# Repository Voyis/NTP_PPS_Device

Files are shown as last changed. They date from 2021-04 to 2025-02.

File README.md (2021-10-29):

# NTP_PPP_Device
ESP32 based board that mimics an GPS with PPS, but using NTP.

## Software Install

This project uses the Arduino library to build the code and flash it onto the ESP32-WROOM-32 from Espressif. After installing the Arduino IDE, you have to first instal the Adafruit SSD1360 library and all it's dependencies. You also need to install the [ESP32 board package](https://docs.espressif.com/projects/arduino-esp32/en/latest/installing.html#installing-using-boards-manager).

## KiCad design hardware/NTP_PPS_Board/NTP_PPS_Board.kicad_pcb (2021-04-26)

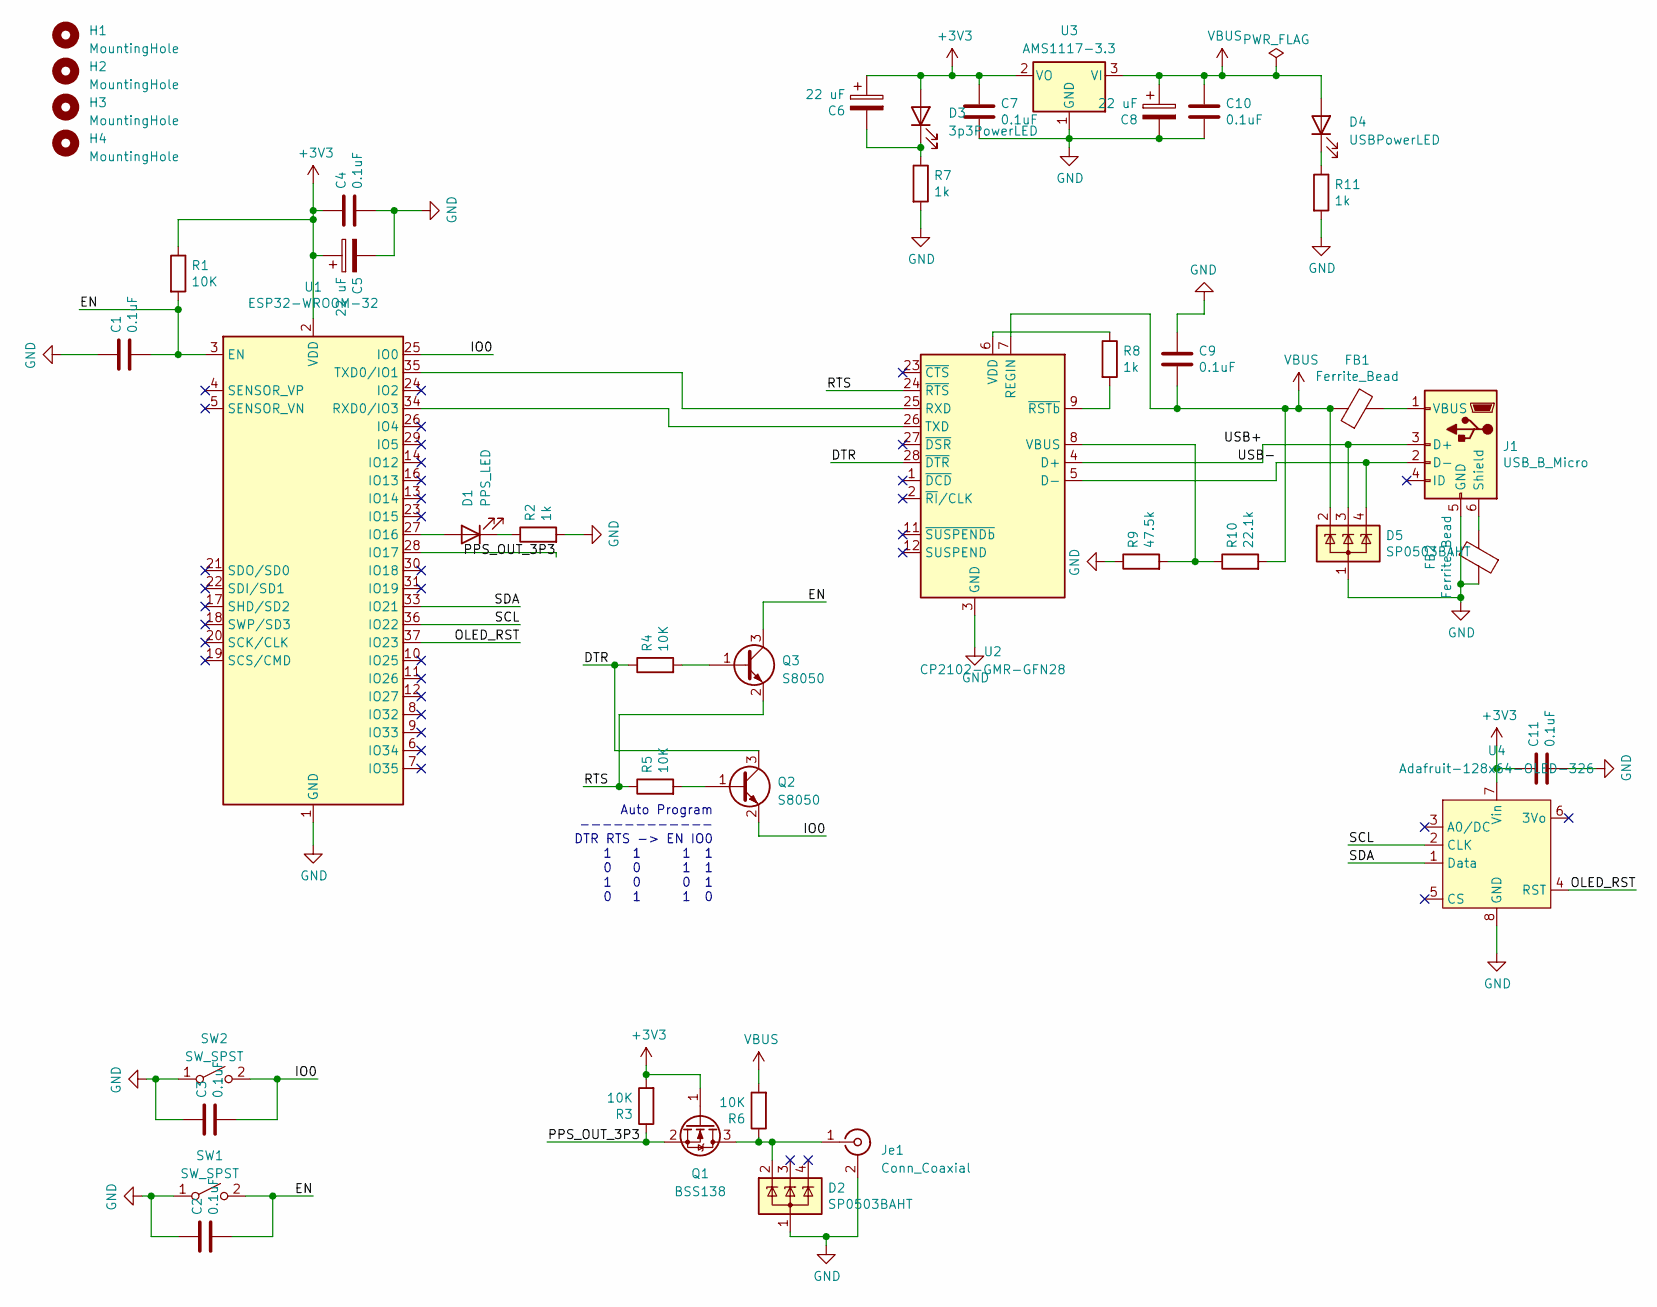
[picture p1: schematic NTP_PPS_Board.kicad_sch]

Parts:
C1, C2, C3, C4, C7, C9, C10, C11: 0.1uF; C_0603_1608Metric; LCSC Part # C14663
C5, C6, C8: 22 uF; CP_Elec_6.3x5.4; LCSC Part # C27783
D1: PPS_LED; LED_0603_1608Metric; LCSC Part # C74343
D2, D5: SP0503BAHT; SOT-143; LCSC Part # C7074
D3: 3p3PowerLED; LED_0603_1608Metric; LCSC Part # C72044
D4: USBPowerLED; LED_0603_1608Metric; LCSC Part # C72044
FB1, FB2: Ferrite_Bead; L_0805_2012Metric; LCSC Part # C88993
H1, H2, H3, H4: MountingHole; MountingHole_3.2mm_M3
J1: USB_B_Micro; MicroUSB-5.9mm; LCSC Part # C393940
Je1: Conn_Coaxial; BNC_TEConnectivity_1478204_Vertical; Digikey Part # A97581-ND
Q1: BSS138; SOT-23; LCSC Part # C112239
Q2, Q3: S8050; SOT-23; LCSC Part # C727137
R1, R3, R4, R5, R6: 10K; R_0603_1608Metric; LCSC Part # C269701
R2, R7, R8, R11: 1k; C_0603_1608Metric; LCSC Part # C269349
R9: 47.5k; R_0603_1608Metric; LCSC Part # C325696
R10: 22.1k; R_0603_1608Metric; LCSC Part # C269476
SW1, SW2: SW_SPST; SW_Push_1P1T_NO_6x6mm_H9.5mm; LCSC Part # C2686880
U1: ESP32-WROOM-32; Digikey Part # 1965-ESP32-WROOM-32E(4MBHIGHTEMP)CT-ND
U2: CP2102-GMR-GFN28; QFN-28-1EP_5x5mm_P0.5mm_EP3.35x3.35mm; LCSC Part # C6568
U3: AMS1117-3.3; SOT-223-3_TabPin2; LCSC Part # C351784
U4: Adafruit-128x64-OLED-326; AdaFruit-0.86-OLED

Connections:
+3V3: C4.1, C5.1, C6.1, C7.1, C11.1, D3.2 (A), Q1.1 (G), R1.1, R3.2, U1.2 (VDD), U3.2 (VO), U4.7 (Vin)
/DTR: Q2.3 (C), R4.1, U2.28 (~DTR)
/EN: C1.2, C2.2, Q3.3 (C), R1.2, SW1.2 (B), U1.3 (EN)
/IO0: C3.2, Q2.2 (E), SW2.2 (B), U1.25 (IO0)
/OLED_RST: U1.37 (IO23), U4.4 (RST)
/PPS_OUT_3P3: Q1.2 (S), R3.1, U1.28 (IO17)
/RTS: Q3.2 (E), R5.1, U2.24 (~RTS)
/SCL: U1.36 (IO22), U4.2 (CLK)
/SDA: U1.33 (IO21), U4.1 (Data)
/USB+: D5.3 (K), J1.3 (D+), U2.4 (D+)
/USB-: D5.4 (K), J1.2 (D-), U2.5 (D-)
GND: C1.1, C2.1, C3.1, C4.2, C5.2, C7.2, C8.2, C9.1, C10.2, C11.2, D2.1 (A), D5.1 (A), FB2.1, J1.5 (GND), Je1.2 (Ext), R2.2, R7.2, R9.1, R11.2, SW1.1 (A), SW2.1 (A), U1.1 (GND), U1.15 (GND), U1.38 (GND), U1.39 (GND), U2.3 (GND), U2.29 (GND), U3.1 (GND), U4.8 (GND)
unnamed: C6.2, D3.1 (K), R7.1
unnamed: D1.1 (K), R2.1
unnamed: D1.2 (A), U1.27 (IO16)
unnamed: D2.2 (K), Je1.1 (In), Q1.3 (D), R6.1
unnamed: D4.1 (K), R11.1
unnamed: FB1.2, J1.1 (VBUS)
unnamed: FB2.2, J1.6 (Shield)
unnamed: Q2.1 (B), R5.2
unnamed: Q3.1 (B), R4.2
unnamed: R8.1, U2.6 (VDD)
unnamed: R8.2, U2.9 (~RSTb)
unnamed: R9.2, R10.1, U2.8 (VBUS)
unnamed: U1.34 (RXD0/IO3), U2.26 (TXD)
unnamed: U1.35 (TXD0/IO1), U2.25 (RXD)
VBUS: C8.1, C9.2, C10.1, D4.2 (A), D5.2 (K), FB1.1, R6.2, R10.2, U2.7 (REGIN), U3.3 (VI)

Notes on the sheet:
Auto Program ------------ DTR RTS -> EN IO0 1 1 1 1 0 0 1 1 1 0 0 1 0 1 1 0

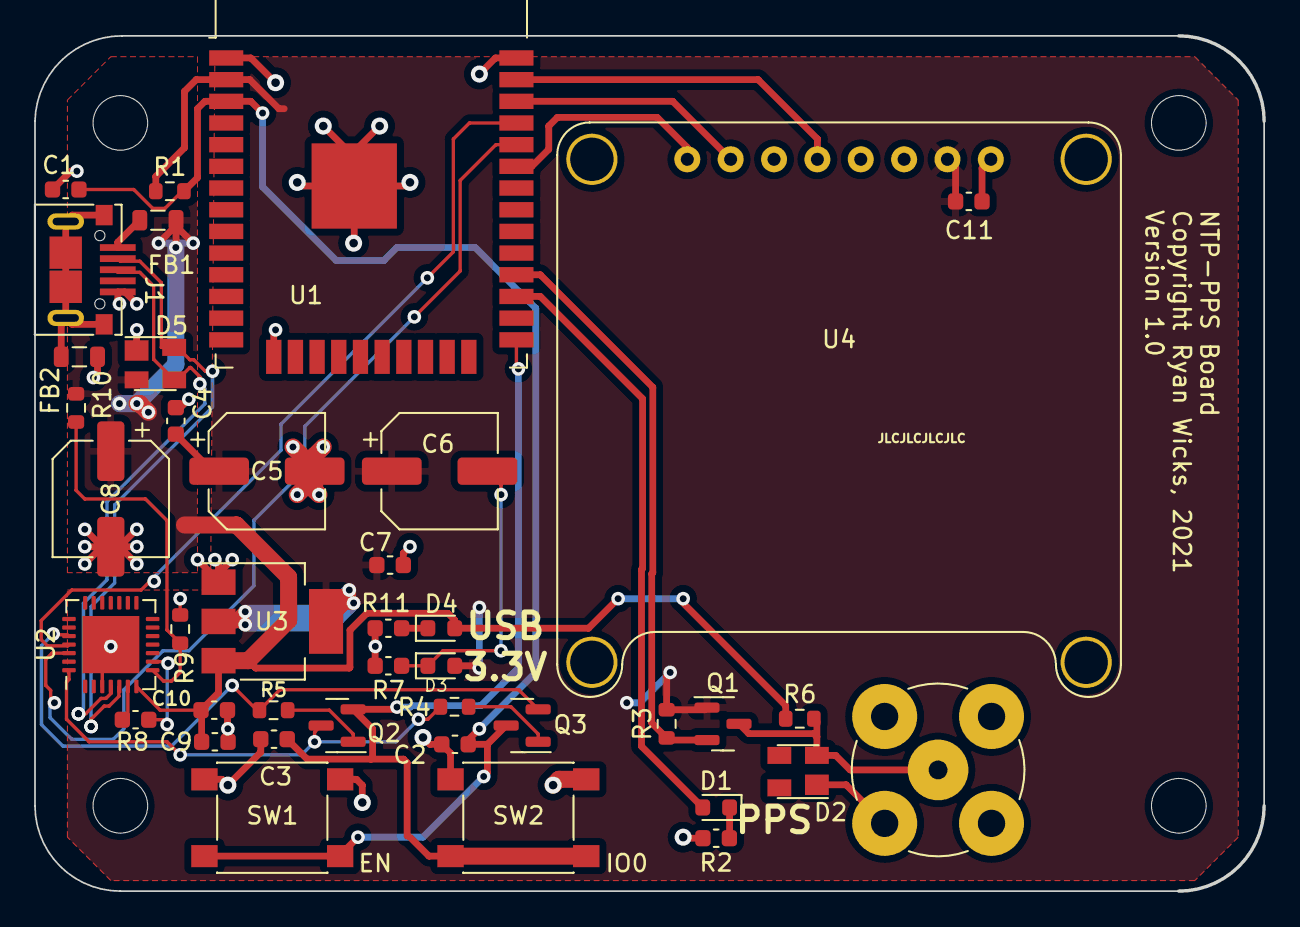
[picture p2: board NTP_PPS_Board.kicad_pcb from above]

Board: 2 copper layers, 72.0 x 50.1 mm, 44 parts (0 on the bottom side), 27 nets.

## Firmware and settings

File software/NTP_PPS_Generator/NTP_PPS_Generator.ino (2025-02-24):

/**
 * NTP_PPP_GENERATOR
 *
 * 9 June 2023
 *
 * This program reads in pps signals an retransmits them at a higher voltage
 *
 * This program connect the NTP-PPS board to a time server, and continually
 * sends out PPS and ZDA pulses every second.
 *
 * It uses the Adafruit SSD1306 library, and any of it's dependencies.
 *
 */

#include <Adafruit_GFX.h>
#include <Adafruit_SSD1306.h>
#include <Arduino.h>
#include <AsyncUDP.h>
#include <WiFi.h>
#include <Wire.h>
#include <esp_sntp.h>
#include <string>
#include <vector>

#include "secrets.h"

#define SCREEN_WIDTH 128 // OLED display width, in pixels
#define SCREEN_HEIGHT 64 // OLED display height, in pixels

#define OLED_RESET -1 // Reset pin # (or -1 if sharing Arduino reset pin)
#define SCREEN_ADDRESS                                                         \
  0x3D ///< See datasheet for Address; 0x3D for 128x64, 0x3C for 128x32
Adafruit_SSD1306 display(SCREEN_WIDTH, SCREEN_HEIGHT, &Wire, OLED_RESET);

const char *ntpServer = "192.168.42.18";
const long gmtOffset_sec = 0;
const int daylightOffset_sec = 0;

const int PPS_OUT_PIN =
    17; // actually gpio 17, but I'm using the DOIT definitions.
const int PPS_OUT_LED = 16;

const int TCP_PORT = 5555;
const int UDP_PORT = 5556;

#define LOGO_HEIGHT 63
#define LOGO_WIDTH 128

static const unsigned char PROGMEM logo_bmp[] = {
    0x00, 0x00, 0x00, 0x00, 0x00, 0x00, 0x00, 0x00, 0x00, 0x00, 0x00, 0x00,
    0x00, 0x00, 0x00, 0x00, 0x00, 0x00, 0x00, 0x00, 0x00, 0x00, 0x00, 0x00,
    0x00, 0x00, 0x00, 0x00, 0x00, 0x00, 0x00, 0x00, 0x00, 0x00, 0x00, 0x00,
    0x00, 0x00, 0x00, 0x00, 0x00, 0x00, 0x00, 0x00, 0x00, 0x00, 0x00, 0x00,
    0x00, 0x00, 0x00, 0x00, 0x00, 0x00, 0x00, 0x00, 0x00, 0x00, 0x00, 0x00,
    0x00, 0x00, 0x00, 0x00, 0x00, 0x00, 0x00, 0x00, 0x00, 0x00, 0x00, 0x00,
    0x00, 0x00, 0x00, 0x00, 0x00, 0x00, 0x00, 0x00, 0x00, 0x00, 0x00, 0x00,
    0x00, 0x00, 0x00, 0x00, 0x00, 0x00, 0x00, 0x00, 0x00, 0x00, 0x00, 0x00,
    0x00, 0x00, 0x00, 0x00, 0x00, 0x00, 0x00, 0x00, 0x00, 0x00, 0x00, 0x00,
    0x00, 0x00, 0x00, 0x00, 0x00, 0x00, 0x00, 0x00, 0x00, 0x00, 0x00, 0x00,
    0x00, 0x00, 0x00, 0x00, 0x00, 0x00, 0x00, 0x00, 0x00, 0x00, 0x00, 0x00,
    0x00, 0x00, 0x00, 0x00, 0x00, 0x00, 0x00, 0x00, 0x00, 0x00, 0x00, 0x00,
    0x00, 0x00, 0x00, 0x00, 0x00, 0x00, 0x00, 0x00, 0x00, 0x00, 0x00, 0x00,
    0x00, 0x00, 0x00, 0x00, 0x00, 0x00, 0x00, 0x00, 0x00, 0x00, 0x00, 0x00,
    0x00, 0x00, 0x00, 0x00, 0x00, 0x00, 0x00, 0x00, 0x00, 0x00, 0x00, 0x00,
    0x00, 0x00, 0x00, 0x00, 0x00, 0x00, 0x00, 0x00, 0x00, 0x00, 0x00, 0x00,
    0x00, 0x00, 0x00, 0x00, 0x00, 0x00, 0x00, 0x00, 0x00, 0x00, 0x00, 0x00,
    0x00, 0x00, 0x00, 0x00, 0x00, 0x00, 0x00, 0x00, 0x00, 0x00, 0x00, 0x00,
    0x00, 0x00, 0x00, 0x00, 0x00, 0x00, 0x00, 0x00, 0x00, 0x00, 0x00, 0x00,
    0x00, 0x00, 0x00, 0x00, 0x00, 0x00, 0x00, 0x00, 0x00, 0x00, 0x00, 0x00,
    0x00, 0x00, 0x00, 0x00, 0x00, 0x00, 0x00, 0x00, 0x00, 0x00, 0x00, 0x00,
    0x00, 0x00, 0x00, 0x00, 0x00, 0x00, 0x00, 0x00, 0x00, 0x00, 0x00, 0x00,
    0x00, 0x00, 0x00, 0x00, 0x00, 0x00, 0x00, 0x00, 0x00, 0x00, 0x00, 0x00,
    0x00, 0x00, 0x00, 0x00, 0x00, 0x00, 0x00, 0x00, 0x00, 0x00, 0x00, 0x00,
    0x00, 0x00, 0x00, 0x00, 0x00, 0x00, 0x00, 0x00, 0x00, 0x00, 0x00, 0x00,
    0x00, 0x00, 0x00, 0x00, 0x00, 0x00, 0x00, 0x00, 0x00, 0x00, 0x00, 0x00,
    0x00, 0x00, 0x00, 0x00, 0x00, 0x00, 0x00, 0x00, 0x00, 0x00, 0x00, 0x00,
    0x00, 0x00, 0x00, 0x00, 0x00, 0x00, 0x00, 0x00, 0x00, 0x00, 0x00, 0x00,
    0x00, 0x00, 0x00, 0x00, 0x00, 0x00, 0x00, 0x00, 0x00, 0x00, 0x00, 0x00,
    0x00, 0x00, 0x00, 0x00, 0x00, 0x00, 0x00, 0x00, 0x00, 0x00, 0x00, 0x00,
    0x00, 0x00, 0x00, 0x00, 0x00, 0x10, 0x00, 0x00, 0x00, 0x00, 0x00, 0x00,
    0x00, 0x00, 0x00, 0x00, 0x00, 0x00, 0x00, 0x00, 0x00, 0x10, 0x00, 0x00,
    0x00, 0x00, 0x00, 0x00, 0x00, 0x00, 0x00, 0x00, 0x00, 0x00, 0x00, 0x00,
    0x00, 0x30, 0x00, 0x00, 0x00, 0x00, 0x00, 0x00, 0x00, 0x00, 0x00, 0x00,
    0x00, 0x00, 0x00, 0x00, 0x00, 0x70, 0x00, 0x00, 0x00, 0x00, 0x00, 0x00,
    0x00, 0x00, 0x00, 0x00, 0x00, 0x00, 0x00, 0x00, 0x00, 0xe0, 0x00, 0x00,
    0x00, 0x00, 0x00, 0x00, 0x00, 0x00, 0x00, 0x00, 0x00, 0x00, 0x00, 0x00,
    0x00, 0xe0, 0x00, 0x00, 0x00, 0x00, 0x00, 0x00, 0x00, 0x00, 0x00, 0x00,
    0x00, 0x00, 0x00, 0x20, 0x01, 0xa0, 0x00, 0x00, 0x00, 0x00, 0x00, 0x00,
    0x00, 0x00, 0x00, 0x00, 0x00, 0x00, 0x00, 0x30, 0x02, 0x80, 0x00, 0x00,
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

hw_timer_t *timer = NULL;
portMUX_TYPE timerMux = portMUX_INITIALIZER_UNLOCKED;

volatile time_t rawtime;
volatile bool second_changed;
char ip_address[16];

WiFiServer server(TCP_PORT);
AsyncUDP udp;
std::vector<WiFiClient> tcp_clients;

/**
 * Generate ZDA and RMC Strings
 */
String generateGPS() {
  struct tm *timeinfo = localtime(const_cast<time_t *>(&rawtime));
  String zda_string;

  // ZDA setup
  char buf[150];
  sprintf(buf, "$GPZDA,%02d%02d%02d.50,%02d,%02d,%04d,00,00*",
          timeinfo->tm_hour, timeinfo->tm_min, timeinfo->tm_sec,
          timeinfo->tm_mday, timeinfo->tm_mon + 1, timeinfo->tm_year + 1900);
  zda_string = String(buf);
  size_t zda_length(zda_string.length());

  uint8_t checksum = 0;
  for (auto i = 0; i < zda_length; ++i) {
    if (buf[i] == '$' || buf[i] == 'I' || buf[i] == '*') {
      continue;
    }
    checksum = checksum ^ buf[i];
  }

  char checkbuf[3];
  sprintf(checkbuf, "%02X", checksum);

  zda_string += checkbuf;
  zda_string += "\r\n";

  // RMC setup
  String rmc_string;

  sprintf(buf,
          "$GPRMC,%02d%02d%02d.00,A,0000.01,N,00000.01,W,0.0,0.0,%02d,%02d,%"
          "04d,0.0,W*",
          timeinfo->tm_hour, timeinfo->tm_min, timeinfo->tm_sec,
          timeinfo->tm_mday, timeinfo->tm_mon + 1, timeinfo->tm_year + 1900);
  rmc_string = String(buf);
  size_t rmc_length(rmc_string.length());

  checksum = 0;
  for (auto i = 0; i < rmc_length; ++i) {
    if (buf[i] == '$' || buf[i] == 'I' || buf[i] == '*') {
      continue;
    }
    checksum = checksum ^ buf[i];
  }

  sprintf(checkbuf, "%02X", checksum);

  rmc_string += checkbuf;
  rmc_string += "\r\n";

  String gps_string;
  gps_string = zda_string + rmc_string;

  return gps_string;
}

/**
 * Method for updating the display.
 */
void printLocalTime() {
  display.clearDisplay();
  display.setCursor(0, 0);
  struct tm *timeinfo = localtime(const_cast<time_t *>(&rawtime));
  display.println(timeinfo, "%B %d %Y\n   %H:%M:%S UTC\n\n");
  display.println("IP Address: ");
  display.println(ip_address);
  display.print("Ports: \nTCP: ");
  display.print(String(TCP_PORT).c_str());
  display.print(" UDP: ");
  display.println(String(UDP_PORT).c_str());
  display.display();

  String gps_string = generateGPS();
  Serial.print((gps_string).c_str());
  udp.broadcastTo((gps_string).c_str(), UDP_PORT);
  for (auto it = tcp_clients.begin(); it != tcp_clients.end(); ++it) {
    if (it->connected()) {
      it->print(gps_string.c_str());
    } else {
      tcp_clients.erase(it);
      --it;
    }
  }
}

/**
 * Interrupt handler for the 1s interrupt.
 */
void IRAM_ATTR onTimer() {
  portENTER_CRITICAL_ISR(&timerMux);
  rawtime += 1;
  digitalWrite(PPS_OUT_PIN, HIGH);
  digitalWrite(PPS_OUT_LED, HIGH);
  second_changed = true;
  portEXIT_CRITICAL_ISR(&timerMux);
}

void setup() {
  Serial.begin(115200);
  Wire.setClock(400000);
  pinMode(PPS_OUT_PIN, OUTPUT);
  pinMode(PPS_OUT_LED, OUTPUT);

  // Set up screen.
  // SSD1306_SWITCHCAPVCC = generate display voltage from 3.3V internally
  if (!display.begin(SSD1306_SWITCHCAPVCC, SCREEN_ADDRESS)) {
    Serial.println(F("SSD1306 allocation failed"));
    for (;;)
      ; // Don't proceed, loop forever
  }
  display.clearDisplay();
  // Show initial display buffer contents on the screen --
  display.drawBitmap(0, 0, logo_bmp, LOGO_WIDTH, LOGO_HEIGHT, 1);
  display.display();
  delay(2000); // Pause for 2 seconds

  display.clearDisplay();
  display.setTextSize(1);
  display.setTextColor(SSD1306_WHITE);
  display.setCursor(25, 0);
  // display.setSize(2);
  display.println("VOYIS NTP PPS");
  display.setCursor(21, 8);
  display.println("Generator V1.0");
  display.display();
  display.printf("\nConnecting to %s\n", WIFI_SSID);
  display.display();
  WiFi.begin(WIFI_SSID, WIFI_PASSWORD);
  while (WiFi.status() != WL_CONNECTED) {
    delay(500);
    display.print(".");
    display.display();
  }
  Serial.println(" CONNECTED");
  IPAddress ip_temp = WiFi.localIP();
  sprintf(ip_address, "%d.%d.%d.%d", ip_temp[0], ip_temp[1], ip_temp[2],
          ip_temp[3]);
  display.display();

  // init and get the time
  struct tm timeinfo;
  configTime(gmtOffset_sec, daylightOffset_sec, ntpServer);
  // sntp_set_sync_interval(15000);
  // sntp_restart();
  if (!getLocalTime(&timeinfo)) {
    display.println("Failed to obtain time");
    return;
  }
  rawtime = mktime(&timeinfo);

  timer = timerBegin(0, 80, true);
  timerAttachInterrupt(timer, &onTimer, true);
  timerAlarmWrite(timer, 1000000, true);
  timerAlarmEnable(timer);

  // disconnect WiFi as it's no longer needed
  // WiFi.disconnect(true);
  // WiFi.mode(WIFI_OFF);
  delay(2000);
  display.clearDisplay();

  server.begin();
}

void loop() {
  // put your main code here, to run repeatedly:
  if (second_changed) {
    second_changed = false;
    printLocalTime();
    delay(100);
    digitalWrite(PPS_OUT_PIN, LOW);
    digitalWrite(PPS_OUT_LED, LOW);
  }

  WiFiClient client = server.available();
  if (client) {
    tcp_clients.push_back(client);
  }

  delay(1);
}

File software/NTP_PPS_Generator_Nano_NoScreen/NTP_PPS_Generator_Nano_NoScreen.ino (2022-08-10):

/**
 * NTP_PPP_GENERATOR For Nano and Ethernet
 * 
 * 29 June 2022
 * 
 * This program connect the NTP-PPS board to a time server, and continually sends out PPS and ZDA pulses every second.
 * 
 * Pulse comes out on pin 13 on the Nano board. You need to update the ethernet library folowing the instructions TimerInterrupt_Generic library due ot timing differences.
 * 
 */
// Select the timers you're using, here ITimer1
#define USE_TIMER_1     true
#define USE_TIMER_2     false


#include <Arduino.h>
#include <string.h>
#include <Vector.h>
#include <SPI.h>
#include <Ethernet.h>
#include <Time.h>
#include "TimerInterrupt_Generic.h"
#include <NTPClient.h>
#include <TimeLib.h>

const char* ntpServer = "192.168.42.18";
const long  gmtOffset_sec = 0;
const int   daylightOffset_sec = 0;

const int PPS_OUT_PIN = 2; 
const int PPS_OUT_LED = LED_BUILTIN;

// the media access control (ethernet hardware) address for the shield:
byte mac[] = { 0xDE, 0xAD, 0xBE, 0xEF, 0xFE, 0xED };  
//the IP address for the shield:
byte ip[] = { 192, 168, 42, 25 };    
// the router's gateway address:
byte gateway[] = { 192, 168, 42, 1 };
// the subnet:
byte subnet[] = { 255, 255, 255, 0 };

const int TCP_PORT = 6000;

volatile bool second_changed;
char ip_address [16];


EthernetServer server (TCP_PORT);
const int ELEMENT_COUNT_MAX = 10;
EthernetClient storage_array[ELEMENT_COUNT_MAX];
Vector <EthernetClient> tcp_clients(storage_array);


EthernetUDP ntpUDP;
NTPClient timeClient(ntpUDP, ntpServer);


//
// Generate ZDA and RMC Strings
//
String generateGPS() {
  time_t rawtime = timeClient.getEpochTime();

  String zda_string;

  //ZDA setup
  char buf[150];
  sprintf(buf, "$GPZDA,%02d%02d%02d.00,%02d,%02d,%04d,00,00*", 
                  hour(rawtime), 
                  minute(rawtime), 
                  second(rawtime),
                  day(rawtime),
                  month(rawtime),
                  year(rawtime));
  zda_string = String(buf);
  size_t zda_length (zda_string.length());

  uint8_t checksum = 0;
  for (auto i = 0; i<zda_length; ++i) {
    if (buf[i] == '$' || buf[i] == 'I' || buf[i] == '*') {
      continue;
    }
    checksum = checksum ^ buf[i];
  }

  char checkbuf[3];
  sprintf(checkbuf, "%02X", checksum);

  zda_string += checkbuf;
  zda_string += "\r\n";


  //RMC setup
  String rmc_string;

  sprintf(buf, "$GPRMC,%02d%02d%02d.00,A,0000.01,N,00000.01,W,0.0,0.0,%02d,%02d,%04d,0.0,W*", 
                  hour(rawtime), 
                  minute(rawtime), 
                  second(rawtime),
                  day(rawtime),
                  month(rawtime),
                  year(rawtime));
  rmc_string = String(buf);
  size_t rmc_length (rmc_string.length());

  checksum = 0;
  for (auto i = 0; i<rmc_length; ++i) {
    if (buf[i] == '$' || buf[i] == 'I' || buf[i] == '*') {
      continue;
    }
    checksum = checksum ^ buf[i];
  }
  
  sprintf(checkbuf, "%02X", checksum);
  
  rmc_string += checkbuf;
  rmc_string += "\r\n"; 

  String gps_string;
  gps_string = zda_string + rmc_string;
  
  return gps_string;
}

//
// Method for updating the display.
//
void printLocalTime()
{
  String gps_string = generateGPS();
  Serial.print((gps_string).c_str());
  for (auto i = 0; i < tcp_clients.size(); ++i) {
    if (tcp_clients[i].connected()) {
      tcp_clients[i].print(gps_string.c_str());
    } else {
      tcp_clients.remove(i);
      --i;
    }
  }
}

#define TIMER_INTERVAL_MS        1000L
//
// Interrupt handler for the 1s interrupt.
//
void onTimer() {
  digitalWrite(PPS_OUT_PIN, HIGH);
  digitalWrite(PPS_OUT_LED, HIGH);
  second_changed = true;
}

void setup() {
  Serial.begin(9600);
  pinMode(PPS_OUT_PIN, OUTPUT);
  pinMode(PPS_OUT_LED, OUTPUT);

  /// initialize the ethernet device
  Ethernet.begin(mac, ip, gateway, subnet);
  
  Serial.println(" CONNECTED");
  sprintf(ip_address, "%d.%d.%d.%d", ip[0], ip[1], ip[2], ip[3] );
  Serial.print(ip_address);

  timeClient.begin();
  timeClient.update();

  // Init timer ITimer1
  ITimer1.init();
  // Interval in unsigned long millisecs
  if (ITimer1.attachInterruptInterval(TIMER_INTERVAL_MS, onTimer)) {
    Serial.println("Starting  ITimer OK, millis() = " + String(millis()));
  } else {
    Serial.println("Can't set ITimer. Select another freq. or timer");
  }
  
  delay(2000);

  server.begin();
  
}

void loop() {
  // put your main code here, to run repeatedly:
  if (second_changed) {
    second_changed = false;
    printLocalTime();
    delay(100);
    digitalWrite(PPS_OUT_PIN, LOW);
    digitalWrite(PPS_OUT_LED, LOW);
    static int i = 0;
    ++i;
  }

  EthernetClient client = server.accept();
  if (client) {
    tcp_clients.push_back(client);
  }
   
  delay(1);
  timeClient.update();
  
}

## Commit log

2021-04-21 First commit.
    [NTP_PPS_Board.kicad_pcb, NTP_PPS_Board.kicad_sch]
2021-04-22 Work on the boards continues.
    [NTP_PPS_Board.kicad_sch]
2021-04-23 Finished schematic.
    [NTP_PPS_Board.kicad_sch]
2021-04-23 Added circuit board
    [NTP_PPS_Board.kicad_pcb]
2021-04-25 Board design finished.
    [NTP_PPS_Board.kicad_pcb, NTP_PPS_Board.kicad_sch]
2021-04-26 Added all the manufacturing files and updated position and BOM files (needed some modifications).
    [NTP_PPS_Board-B_Cu.gbr, NTP_PPS_Board-B_Mask.gbr, NTP_PPS_Board-B_Paste.gbr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]
2021-05-12 Time working, Wifi working, display working. Still needs serial and socket ZDA out.
2022-08-10 Added headless NTP nano generator arduino code.

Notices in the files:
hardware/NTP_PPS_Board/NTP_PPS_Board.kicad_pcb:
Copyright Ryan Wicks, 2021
